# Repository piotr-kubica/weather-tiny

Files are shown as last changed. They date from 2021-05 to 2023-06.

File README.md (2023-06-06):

BTC  


# Tiny weather station based on TTGO T5 V2.3.1 (ESP32 with 2.13" e-ink display)

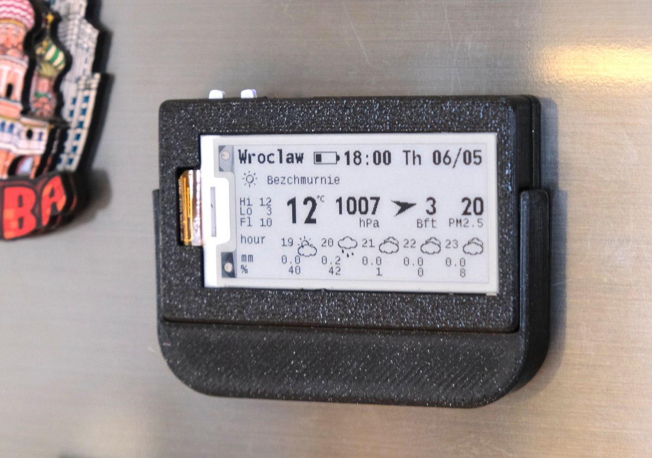
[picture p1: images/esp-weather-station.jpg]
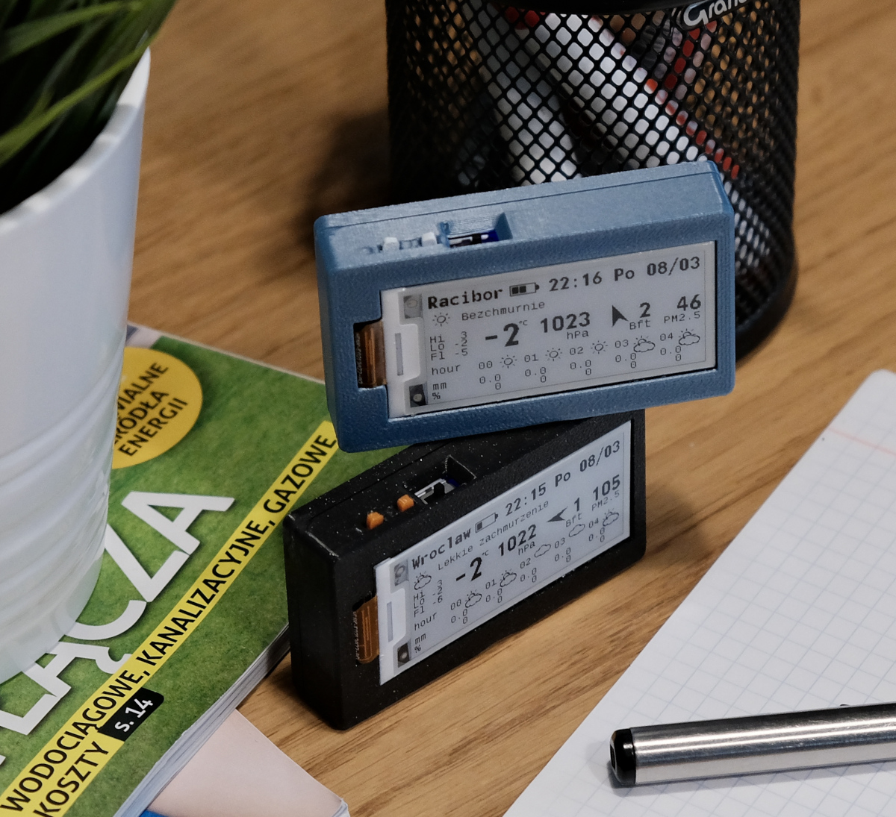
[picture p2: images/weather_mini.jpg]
[](/images/esp-weather-station.jpg) [](/images/weather_mini.jpg) 

### This project is licensed under GNU General Public License v2.0
The GNU GPL is the most widely used free software license and has a strong copyleft requirement. When distributing derived works, the source code of the work must be made available under the same license. There are multiple variants of the GNU GPL, each with different requirements.

### 🔸NOTE🔸
Second version of the firmware is currently being developed.
The goals include: enhanced performance, increased (4+ weeks) battery life, easier configurability, integration with external systems.

### Features

- wireless and rechargable
- weather description including temperature, pressure, wind
- rain forecast
- air quality index
- multiple locations
- easy wireless setup using smartphone/PC
- fridge mount
- refreshes every 15 min.

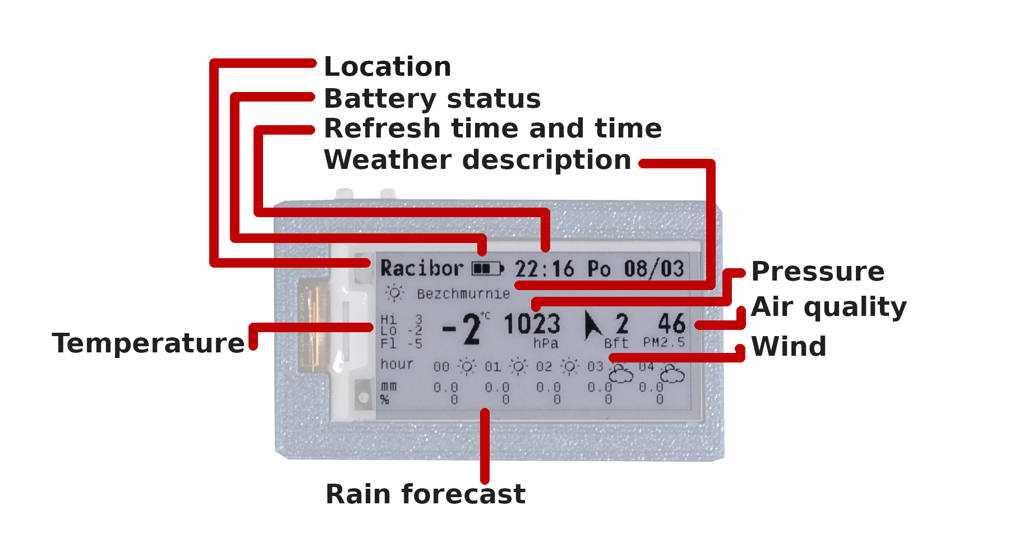
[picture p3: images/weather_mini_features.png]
[](/images/weather_mini_features.png)

### User guide

#### Device configuration

Turn on device. 
Reset to enable configuration.
Connect to `weather-wifi` device access point.
Go to 192.168.4.1/config if not redirected.
Provide wireless lan ssid and password.
Provide locations for which information should be fetched.
Submit config form.
After a successful validation device displays weather information for given location.

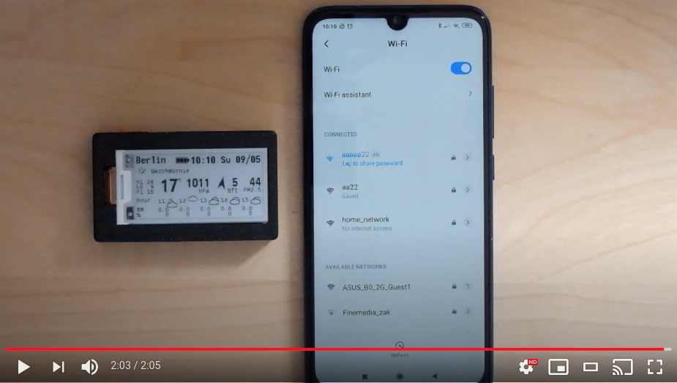
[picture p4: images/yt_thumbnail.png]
YT video thumbnail (https://youtu.be/SJgQPxBXJxA)


#### Device usage
Switch between locations using top left button. \
Refresh current location using top right button. \
Reset device using bottom button. \
Turn on/off device using top switch.
\
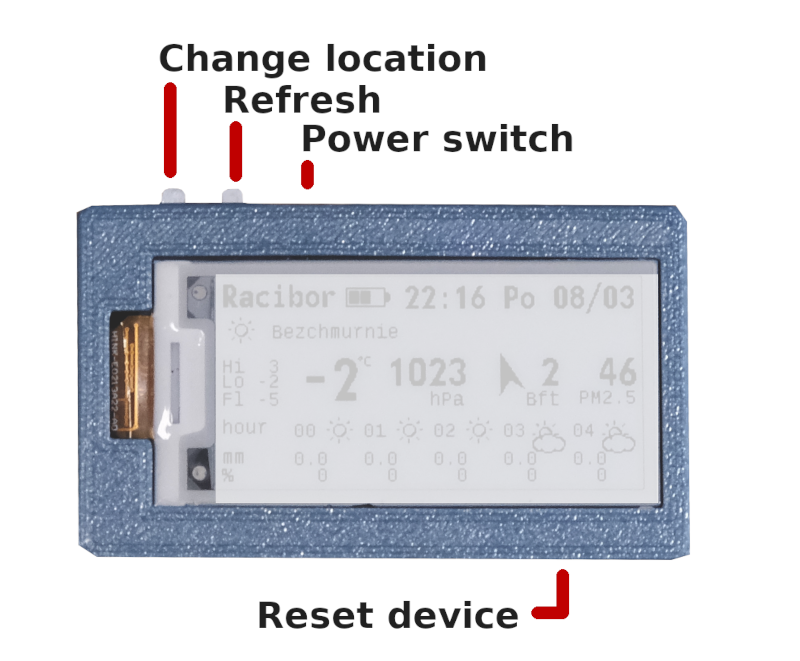
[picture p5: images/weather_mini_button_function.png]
[](/images/weather_mini_button_function.png)

### Hardware
To assemble the device yourself you will need
- TTGO T5 V2.3
- small LiPo battery cell with JST-BEC connector (980mAh 3.7V, size: 50x34x6mm)
- 3D printed case (see: stl files)
- M3 bolt (6mm long) [4]
- magnet 5x12mm (for fridge mount) [5]
- 10k resistor [1]
- thermo sleeve [3]
- small tactile button 4.5x4.5x3mm [2]
- (optional) poly foam or similar to put inside case with battery, so it does not move

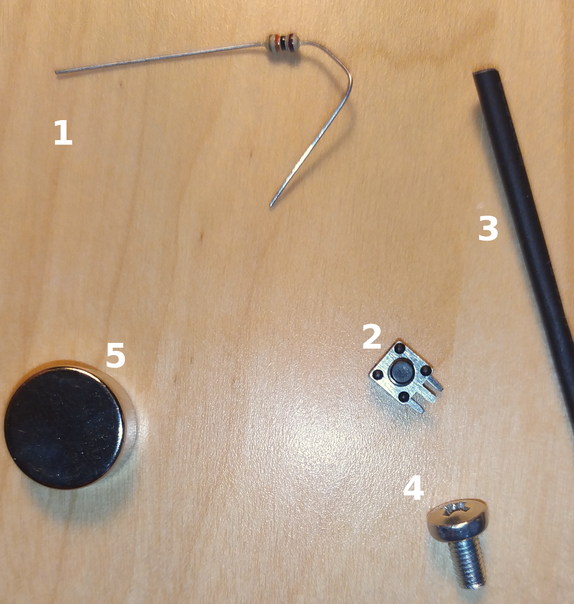
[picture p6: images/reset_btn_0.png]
[](/images/reset_btn_0.png)
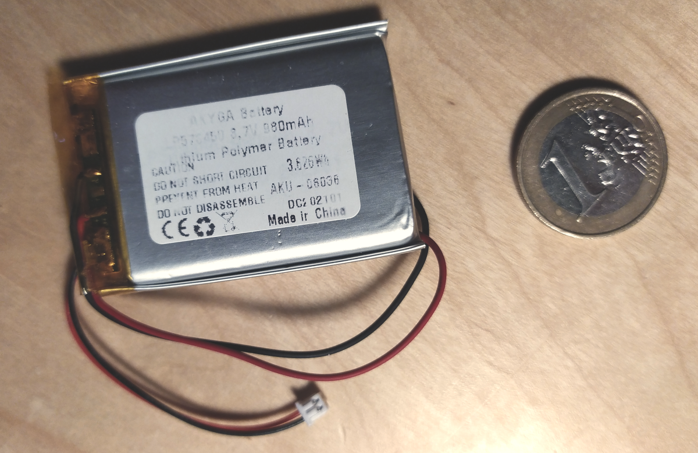
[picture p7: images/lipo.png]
[](/images/lipo.png)

### Assembly
Device comes with two buttons (used for refresh and location change).
The missing reset device button needs to be added by using tactile button and a pull-down resistor.
Create the pull-down resistor by soldering the resistor to GND and pin 34.
Solder the tactile button to pins 34 and 3V3.

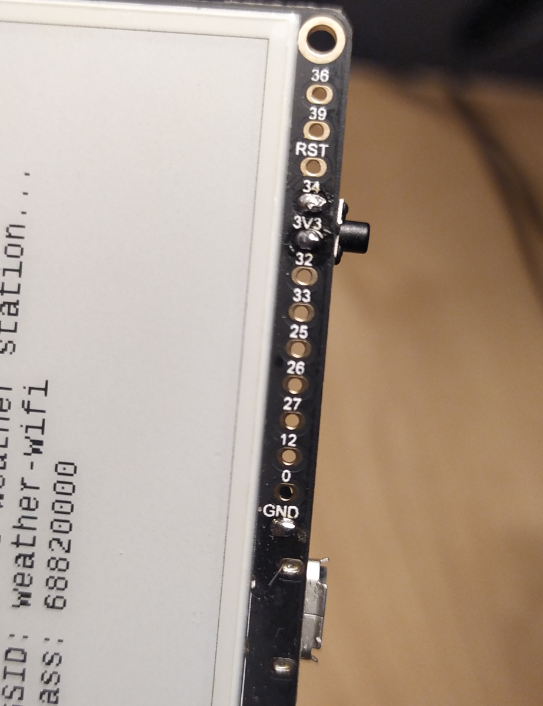
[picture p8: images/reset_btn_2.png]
[](/images/reset_btn_2.png)
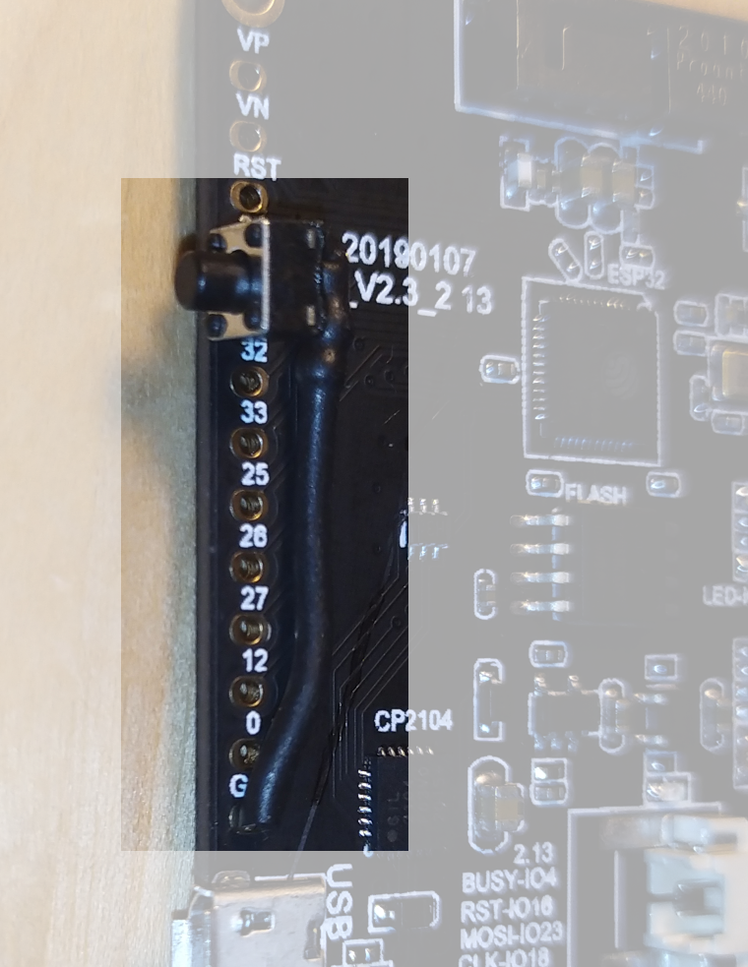
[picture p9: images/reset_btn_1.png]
[](/images/reset_btn_1.png) 

Insert TTGO to the 3D printed case. Connect the LiPo cell. 
Mount the case using M3 bolt.

### Software

#### License
Project source code is licensed under GPL2 (including source code and stl).
This does not include external libraries and used fonts.

#### Installation
##### Setup Arduino IDE to be used with ESP32.
You can do this in this tutorial
https://randomnerdtutorials.com/installing-the-esp32-board-in-arduino-ide-windows-instructions/

##### Install external libs
- Adafruit GFX Library
- GxEPD.h - includes e-ink screen drivers. I have used GxGDE0213B72B or GxDEPG0213BN depending on device display version
- ArduinoJson - for handling API responses 
- AsyncTCP - used for API requests
- ESPAsyncWebServer - used for config server
- Preferences - used for data storage

You can find GxGDE0213B72B and GxDEPG0213BN drivers <a href="https://github.com/Xinyuan-LilyGO/LilyGO-T-Echo/tree/7066ced313bf4ca941c6edbcb20ea3b1aaf0ea95/lib/GxEPD/src">here</a>
  
Use font files generated by fontconvert which can be found inside libraries/Adafruit_GFX_library/Fonts.
You can also download these fonts (free to use) and use fontconvert tool to create them yourself.

##### API keys
External APIs are used to fetch data. 
These are free to use services:
- https://positionstack.com/ to fetch location position
- https://aqicn.org/api/pl/ for air quality
- https://openweathermap.org/api for weather data
- https://timezonedb.com/api for date and time

Register and obtain the keys. Then replace the api keys in config.h file.

##### Upload sketch to device
Verify and upload the weather_mini.ino sketch.
After successful upload turn on the device and configure it as shown in [device configuration](#device-configuration) section.
See the example output from [serial monitor](monitor_log.txt) for a successful device configuration.

### Support

If you have found this project useful you can buy me a cup of coffee 







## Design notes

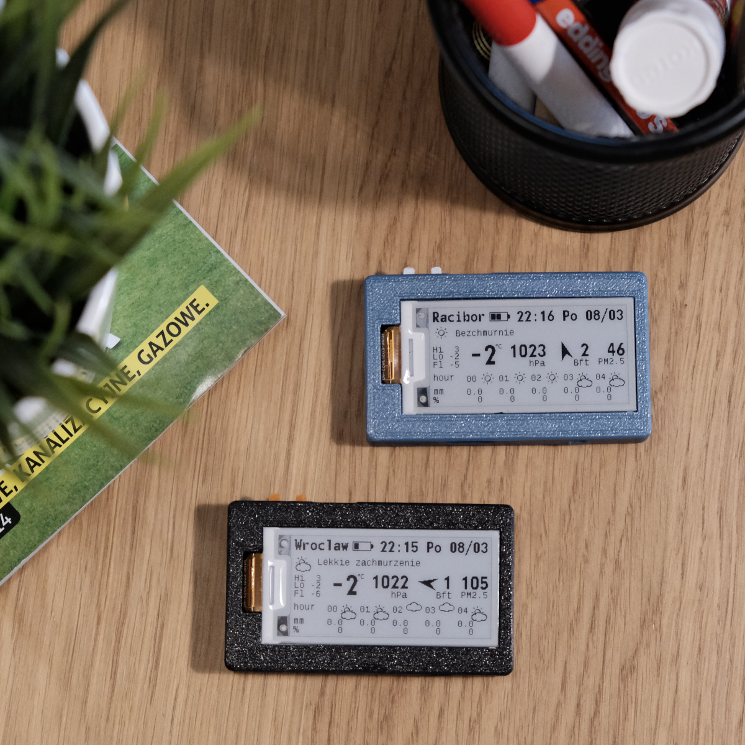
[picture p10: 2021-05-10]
images/weather_mini2.jpg

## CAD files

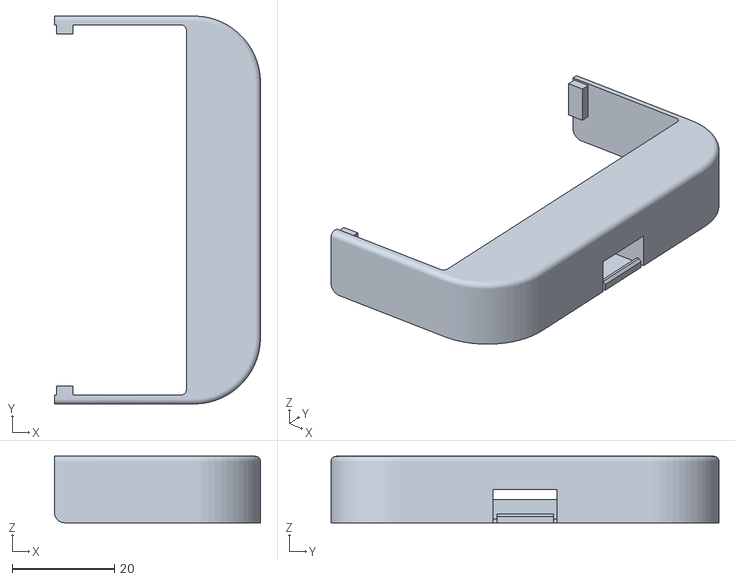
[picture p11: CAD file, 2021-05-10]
stl/mount.stl
40.2 x 75.8 x 13.0

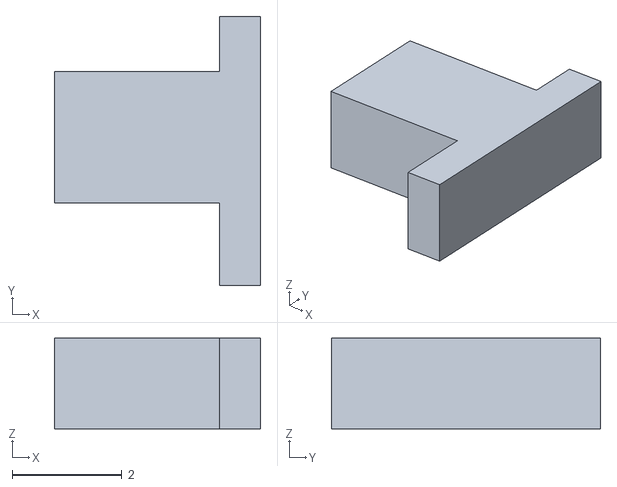
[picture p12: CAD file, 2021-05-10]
stl/btn-right.stl
3.75 x 4.90 x 1.65

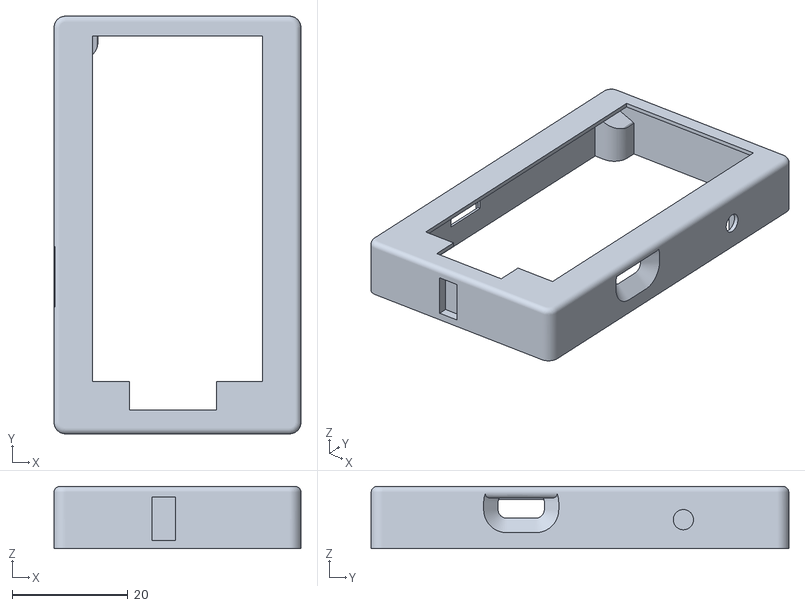
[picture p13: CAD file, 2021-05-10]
stl/front.stl
42.8 x 72.3 x 10.8

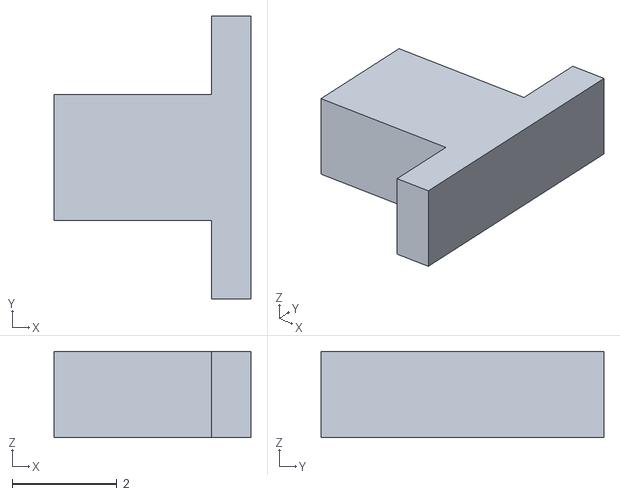
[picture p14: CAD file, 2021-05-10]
stl/btn-left.stl
3.75 x 5.40 x 1.65

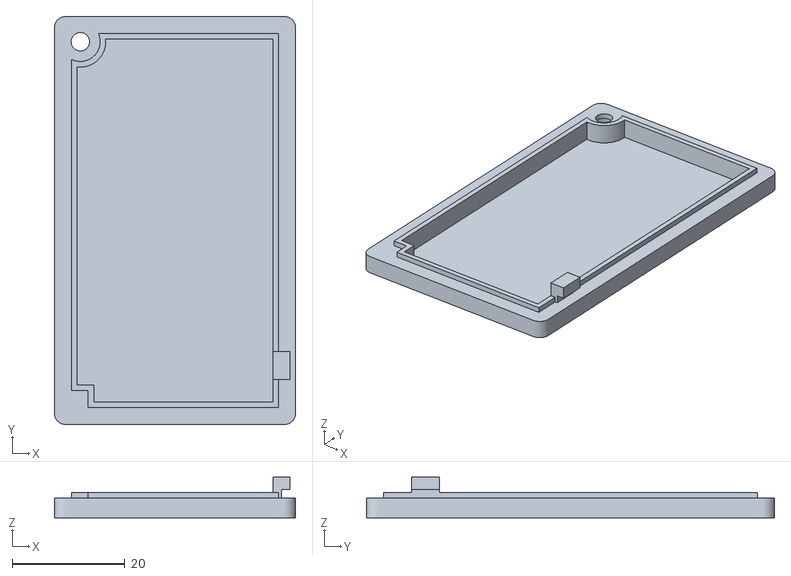
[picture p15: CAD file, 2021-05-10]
stl/back.stl
42.8 x 72.3 x 7.25

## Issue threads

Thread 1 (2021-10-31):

Add pressure trend indicating arrow

piotr-kubica, 2021-10-31:
Add pressure trend indicating arrow below pressure value pointing upwards/downwards or no arrow for no big change in pressure.

rdulak, 2022-02-11:
Great project !!! Revelation !!!
Unfortunately I stopped at the connection with api.positionstack.
I get the response "Error 520 Web server is returning an unknown error".
Is a Free account enough for the module to work.
Even sending a request from the browser I do not get an answer.
I ask for osugestions. Thank you.

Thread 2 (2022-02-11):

api.positionstack ---> Error 520

rdulak, 2022-02-11:
Great project !!! Revelation !!!
Unfortunately I stopped at the connection with api.positionstack.
I get the response "Error 520 Web server is returning an unknown error".
Is a Free account enough for the module to work.
Even sending a request from the browser I do not get an answer.
I ask for osugestions. Thank you.

piotr-kubica, 2022-02-11:
> Great project !!! Revelation !!!
Thank you :)

> I get the response "Error 520 Web server is returning an unknown error".
Seems to be a server side problem. You could contact positionstack and ask if your request is valid.

> Is a Free account enough for the module to work.
with free tier should be ok (25.000 Requests at the time of writing)

Device does request (by default) every 15 mins so 15*24 per day -> this is optimistic estimation, because in case the request fails there will be a retry.

Also I see possible improvement: request during night could be done sparsely (1/hour) and during datetime reduce from 4 to 3 per hour to improve battery life

rdulak, 2022-02-11:
Is your system working fine at the moment?
To my eye, something is on the server side ...
"All systems down" :(
https://status.positionstack.com/

piotr-kubica, 2022-02-11:
same for me

Closed 2022-02-11.

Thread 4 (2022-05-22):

Daily forecast for rain

mattcalavera, 2022-05-22:
Hi! Many thanks for your beautiful works!!
Could please be possibile to switch between hourly rain forecast and daily rain forecast, instead (or in the same way) now we switch from the two location??

Thanks
#Enhancements

piotr-kubica, 2022-06-03:
No problem. Feel free to change code to your liking

piotr-kubica, 2023-06-06:
@mattcalavera
the location change happens on button press which wakes up the device. The cause of this wakeup is handled in this function https://github.com/piotr-kubica/weather-tiny/blob/19708bc4932226a28e3403b3fe56d250bcc236e3/weather_tiny/weather_tiny.ino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

The response from OpenWeatherApi is handled in this function https://github.com/piotr-kubica/weather-tiny/blob/19708bc4932226a28e3403b3fe56d250bcc236e3/weather_tiny/weather_tiny.ino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

Also, look up the API to see how it's structured https://openweathermap.org/api

I hope this helps you with your changes.

mattcalavera, 2023-06-09:
Hi! I start with saving forecasts for next 5 days instead of next 2 days : in

https://github.com/piotr-kubica/weather-tiny/blob/19708bc4932226a28e3403b3fe56d250bcc236e3/weather_tiny/api_request.h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

How can I save forecasts for next 5 days?? (in the api response there are next 7 days!)

mattcalavera, 2023-06-10:
Ok, after a few work I obtain next 5 days rain forecast.... I'll fork this project with the new code if someone is interested

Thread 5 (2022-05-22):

Battery Icon

mattcalavera, 2022-05-22:
the battery icon remain still with the bolt inside as if it where ever on charge also when it's powered only by battery

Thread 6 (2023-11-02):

2.13英寸得屏幕显示不全，这个应该是2.3英寸屏幕尺寸得项目。

plutosherry, 2023-11-02:
2.13英寸得屏幕显示不全，这个应该是2.3英寸屏幕尺寸得项目。
修改了

`
//#define SCREEN_WIDTH   250
//#define SCREEN_HEIGHT  122

#define SCREEN_WIDTH   212
#define SCREEN_HEIGHT  104
`
但依旧不能完整显示

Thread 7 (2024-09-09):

Compile Error with latest library versions

bix2702, 2024-09-09:
I just found your very nice weather tiny project and tried to replicate. I used the latest versions of all libraries and Arduino Studio. Unfortunately the build fails, probably because of changes in some libs. Especially the ArdunioJson and AsyncTCP got a lot of changes.
Maybe it's just smal thing but it's too complex for me the rewrite it.

Would you mind to try to compile it against the latest libraries? Or could you write which versions of each library you used?

piotr-kubica, 2024-09-10:
Hi, thanks for writing!

> Or could you write which versions of each library you used?

I'm sorry I didn't put the version number next to libraries.
Your best bet would be to download all libs from around May 2021 and then trying to compile.

> Would you mind to try to compile it against the latest libraries?

Sorry, I've already moved to implementing second iteration of this device.
I hope I can share the ready project with you as soon as I am ready to release some meaningful and working code.

bix2702, 2024-09-11:
Hi Piotr,
thx for quick answer! I will try and report.

Of course, I would be very interessted in your second iteration.

Kind  Regards

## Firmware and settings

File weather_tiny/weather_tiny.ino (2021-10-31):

// ----------------------------------
// DISPLAY --------------------------
// ----------------------------------
#include <SPI.h>
#include <GxEPD.h>

#include <GxGDE0213B72B/GxGDE0213B72B.h> // 2.13" b/w
// #include <GxDEPG0213BN/GxDEPG0213BN.h>  // 2.13" b/w newer panel

#include <GxIO/GxIO_SPI/GxIO_SPI.h>
#include <GxIO/GxIO.h>

#define SPI_MOSI 23
#define SPI_MISO -1
#define SPI_CLK 18
#define ELINK_SS 5
#define ELINK_BUSY 4
#define ELINK_RESET 16
#define ELINK_DC 17

GxIO_Class io(SPI, ELINK_SS, ELINK_DC, ELINK_RESET);
GxEPD_Class display(io, ELINK_RESET, ELINK_BUSY);

#define SCREEN_WIDTH   250
#define SCREEN_HEIGHT  122

// ----------------------------------
// LIBS -----------------------------
// ----------------------------------
#define ARDUINOJSON_USE_DOUBLE 1

#include <WiFi.h>
#include <HTTPClient.h>
#include <ArduinoJson.h>
#include <time.h>
#include <DNSServer.h>
#include <AsyncTCP.h>
#include <ESPAsyncWebServer.h>
#include <rom/rtc.h> 
#include <Preferences.h>

#define ADC_PIN 35
#define WAKE_BTN_PIN 39

// ----------------------------------
// FONTS ----------------------------
// ----------------------------------

#include <Fonts/Monofonto10pt.h>
#include <Fonts/Monofonto12pt.h>
#include <Fonts/Monofonto18pt.h>
#include <Fonts/MeteoCons8pt.h>
#include <Fonts/MeteoCons10pt.h>
#include <Fonts/Cousine6pt.h>

// ----------------------------------
// LOCAL FILES AND DECLARATIONS -----
// ----------------------------------

#include "fmt.h"
#include "i18n.h"
#include "config.h"
#include "units.h"
#include "api_request.h"
#include "display.h"
#include "view.h"

#define MEMORY_ID "mem"
#define LOC_MEMORY_ID "loc"

#define NOT_SET_MODE 0
#define CONFIG_MODE 1
#define VALIDATING_MODE 2
#define OPERATING_MODE 3

// http server for obtaining configuration
DNSServer dnsServer;
AsyncWebServer server(80);
Preferences preferences;

int cached_MODE = 0;
int curr_loc = 0;

struct WeatherRequest weather_request;
struct AirQualityRequest airquality_request;
struct GeocodingNominatimRequest location_request;
struct TimeZoneDbRequest datetime_request;

int location_cnt = 0;
struct Location location[2];
struct WifiCredentials wifi;
struct View view;

int get_mode(bool cached_mode=false);
DynamicJsonDocument deserialize(WiFiClient& resp_stream, const int size, bool is_embeded=false);


// ----------------------------------
// FUNCTION DEFINITIONS -------------
// ----------------------------------

template<typename T>
T value_or_default(JsonObject jobj, String key, T default_value) {
    if (!jobj.containsKey(key)) {
        return default_value;
    } else {
        return jobj[key];
    }
}


template<typename T>
T nested_value_or_default(JsonObject parent_jobj, String key, String nested_key, T default_value) {
    if (!parent_jobj.containsKey(key)) {
        return default_value;
    } else {
        return parent_jobj[key][nested_key];
    }
}


void update_header_view(View& view, bool data_updated) {
    view.location = location[curr_loc].name.substring(0,7);
    view.battery_percent = get_battery_percent(analogRead(ADC_PIN));
    int percent_display = view.battery_percent;
    
    if (percent_display > 100) {
        percent_display = 100;
    }
    view.battery_percent_display = String(percent_display) + "%";
    view.datetime = header_datetime(&datetime_request.response.dt, data_updated);
}


void update_air_quality_view(View& view, bool data_updated) {
    if (!data_updated) {
        return;
    }
    view.aq_pm25 = left_pad(String(airquality_request.response.pm25), 3);
    view.aq_pm25_unit = "PM2.5";
}


void update_weather_view(View& view, bool data_updated) {
    if (!data_updated) {
        return;
    }
    view.weather_icon = String(icon2meteo_font(weather_request.hourly[0].icon));
    
    String descr = weather_request.hourly[0].descr;
    view.weather_desc = capitalize(descr);
    
    view.temp_curr = left_pad(String(weather_request.hourly[0].temp), 3);
    view.temp_unit = '*';  // celsius
    view.temp_high = "Hi" + left_pad(String(weather_request.hourly[0].max_t), 3);
    view.temp_low = "Lo" + left_pad(String(weather_request.hourly[0].min_t), 3);
    view.temp_feel = "Fl" + left_pad(String(weather_request.hourly[0].feel_t), 3);

    view.pressure = left_pad(String(weather_request.hourly[0].pressure), 4);
    view.pressure_unit = "hPa";

    view.wind = left_pad(String(weather_request.hourly[0].wind_bft), 2);
    view.wind_deg = weather_request.hourly[0].wind_deg;

    for (int i = 0; i < PERCIP_SIZE; i++) {
        view.percip_time[i] = ts2H(weather_request.rain[i].date_ts + datetime_request.response.gmt_offset);
        view.percip_icon[i] = String(icon2meteo_font(weather_request.rain[i].icon));

        float cumulative_percip = weather_request.rain[i].snow + weather_request.rain[i].rain;
        if (cumulative_percip > 0) {
            view.percic_pop[i] = left_pad(fmt_2f1(cumulative_percip), 4);
        } else {
            view.percic_pop[i] = left_pad(String(min(weather_request.rain[i].pop, 99)) + "%", 4);
        }

        // temp TODO rename from percip
        view.percip[i] = fmt_2f1(weather_request.rain[i].feel_t);
    }
}


void update_location(GeocodingNominatimResponse& location_resp, JsonObject& jobj) {
    location_resp.lat = jobj["data"][0]["latitude"].as<float>();
    location_resp.lon = jobj["data"][0]["longitude"].as<float>();
    location_resp.label = String(jobj["data"][0]["label"].as<char*>()).substring(0, 25);
}


void update_datetime(TimeZoneDbResponse& datetime_resp, JsonObject& jobj) {
    datetime_resp.dt = jobj["timestamp"].as<int>();
    datetime_resp.gmt_offset = jobj["gmtOffset"].as<int>();
    datetime_resp.dst = jobj["dst"].as<int>();
}


void update_current_weather(WeatherResponseHourly& hourly, JsonObject& root) {
    hourly.date_ts = root["current"]["dt"].as<int>();
    hourly.sunr_ts = root["current"]["sunrise"].as<int>();
    hourly.suns_ts = root["current"]["sunset"].as<int>();
    hourly.temp = kelv2cels(root["current"]["temp"].as<float>());
    hourly.feel_t = kelv2cels(root["current"]["feels_like"].as<float>());
    hourly.max_t = kelv2cels(root["daily"][0]["temp"]["max"].as<float>());
    hourly.min_t = kelv2cels(root["daily"][0]["temp"]["min"].as<float>());
    hourly.pressure = root["current"]["pressure"].as<int>();
    hourly.clouds = root["current"]["clouds"].as<int>();
    hourly.wind_bft = wind_ms2bft(root["current"]["wind_speed"].as<float>());
    hourly.wind_deg = root["current"]["wind_deg"].as<int>();
    hourly.icon = String(root["current"]["weather"][0]["icon"].as<char*>()).substring(0, 2);
    hourly.descr = root["current"]["weather"][0]["description"].as<char*>();
    hourly.pop = round(root["hourly"][1]["pop"].as<float>() * 100);
    hourly.snow = value_or_default(root["current"], "snow", 0.0f);
    hourly.rain = value_or_default(root["current"], "rain", 0.0f);
}


void update_forecast_weather(WeatherResponseDaily& daily, JsonObject& root, const int day_offset) {
    daily.date_ts = root["daily"][day_offset]["dt"].as<int>();
    daily.max_t = kelv2cels(root["daily"][day_offset]["temp"]["max"].as<float>());
    daily.min_t = kelv2cels(root["daily"][day_offset]["temp"]["min"].as<float>());
    daily.wind_bft = wind_ms2bft(root["daily"][day_offset]["wind_speed"].as<float>());
    daily.wind_deg = root["daily"][day_offset]["wind_deg"].as<int>();
    daily.pop = round(root["daily"][day_offset]["pop"].as<float>() * 100);
    daily.snow = value_or_default(root["daily"][day_offset], "snow", 0.0f);
    daily.rain = value_or_default(root["daily"][day_offset], "rain", 0.0f);
}


void update_percip_forecast(WeatherResponseRainHourly& percip, JsonObject& root, const int hour_offset) {
    percip.date_ts = root["hourly"][hour_offset]["dt"].as<int>();
    percip.pop = round(root["hourly"][hour_offset]["pop"].as<float>() * 100);
    percip.snow = nested_value_or_default(root["hourly"][hour_offset], "snow", "1h", 0.0f);
    percip.rain = nested_value_or_default(root["hourly"][hour_offset], "rain", "1h", 0.0f);
    percip.feel_t = kelv2cels1(root["hourly"][hour_offset]["feels_like"].as<float>());
    percip.icon = String(root["hourly"][hour_offset]["weather"][0]["icon"].as<char*>()).substring(0, 2);
}


bool location_handler(WiFiClient& resp_stream, Request request) {
    const int json_size = 20 * 1024;
    DynamicJsonDocument doc = deserialize(resp_stream, json_size, true);
    JsonObject api_resp = doc.as<JsonObject>();

    if (api_resp.isNull()) {
        return false;
    }
    location_request = GeocodingNominatimRequest(request);
    GeocodingNominatimResponse& location_resp = location_request.response;
    Serial.print("Geocoding...");
    update_location(location_resp, api_resp);
    location_resp.print();
    return true;
}


bool datetime_handler(WiFiClient& resp_stream, Request request) {
    const int json_size = 10 * 1024;
    DynamicJsonDocument doc = deserialize(resp_stream, json_size, true);
    JsonObject api_resp = doc.as<JsonObject>();

    if (api_resp.isNull()) {
        return false;
    }
    datetime_request = TimeZoneDbRequest(request);
    TimeZoneDbResponse& datetime_response = datetime_request.response;
    update_datetime(datetime_response, api_resp);
    datetime_response.print();
    return true;
}
    

bool weather_handler(WiFiClient& resp_stream, Request request) {
    const int json_size = 35 * 1024;
    DynamicJsonDocument doc = deserialize(resp_stream, json_size);
    JsonObject api_resp = doc.as<JsonObject>();

    if (api_resp.isNull()) {
        return false;
    }
    weather_request = WeatherRequest(request);
    WeatherResponseHourly& hourly = weather_request.hourly[0];
    WeatherResponseDaily& next_day = weather_request.daily[0];
    WeatherResponseDaily& second_next_day = weather_request.daily[1];

    update_current_weather(hourly, api_resp);
    hourly.print();
    update_forecast_weather(next_day, api_resp, 1);
    next_day.print();
    update_forecast_weather(second_next_day, api_resp, 2);
    second_next_day.print();

    for (int hour = 0; hour < 5; hour++) {
        int offset = hour + 1;
        update_percip_forecast(weather_request.rain[hour], api_resp, offset);
        weather_request.rain[hour].print();
    }
    return true;
}


bool air_quality_handler(WiFiClient& resp_stream, Request request) {
    const int json_size = 6 * 1024;
    DynamicJsonDocument doc = deserialize(resp_stream, json_size);
    JsonObject api_resp = doc.as<JsonObject>();
    
    if (api_resp.isNull()) {
        return false;
    }
    if (!String(api_resp["status"].as<char*>()).equals("ok")) {
        return false;
    }
    airquality_request = AirQualityRequest(request);
    
    if (api_resp["data"]["iaqi"].containsKey("pm25")) {
        airquality_request.response.pm25 = api_resp["data"]["iaqi"]["pm25"]["v"].as<int>();
    } else if (api_resp["data"]["forecast"]["daily"].containsKey("pm25")) {
        airquality_request.response.pm25 = api_resp["data"]["forecast"]["daily"]["pm25"][0]["max"].as<int>();
    }
    airquality_request.response.print();
    
    return true;
}


DynamicJsonDocument deserialize(WiFiClient& resp_stream, const int size, bool is_embeded) {
    // https://arduinojson.org/v6/assistant/
    Serial.print("\nDeserializing json, size:" + String(size) + " bytes...");
    DynamicJsonDocument doc(size);
    DeserializationError error;
    
    if (is_embeded) {
        String stream_as_string = resp_stream.readString();
        int begin = stream_as_string.indexOf('{');
        int end = stream_as_string.lastIndexOf('}');
        Serial.print("\nEmbeded json algorithm obtained document...\n");
        String trimmed_json = stream_as_string.substring(begin, end+1);
        Serial.println(trimmed_json);
        error = deserializeJson(doc, trimmed_json);
    } else {
        error = deserializeJson(doc, resp_stream);
    }
    if (error) {
        Serial.print(F("\ndeserialization error:"));
        Serial.println(error.c_str());
    } else {
        Serial.println("deserialized.");
    }
    Serial.println("");
    return doc;
}


int get_battery_percent(int adc_value) {
    float voltage = adc_value / 4095.0 * 7.5;
    Serial.println("Battery voltage ~" + String(voltage) + "V");
    if (voltage > 4.35) {
        return 101;  // charging / DC powered
    }
    if (voltage > 4.2) {
        return 100;
    } 
    if (voltage < 3.3) {
        return 1;
    }
    int percent = (int)((voltage - 3.3)/(4.1 - 3.3)*99) + 1;
    Serial.println("Battery percent: " + String(percent) + "%");
    return percent;
}


bool http_request_data(WiFiClient& client, Request request, unsigned int retry=3) {
    
    bool ret_val = false;

    while(!ret_val && retry--) {
        ret_val = true;
        client.stop();
        HTTPClient http;
        Serial.printf("\nHTTP connecting to %s%s [retry left: %s]", request.server.c_str(), request.path.c_str(), String(retry).c_str());
        http.begin(client, request.server, 80, request.path);
        int http_code = http.GET();
        
        if(http_code == HTTP_CODE_OK) {
            Serial.println("\nHTTP connection established");
            if (!request.handler(http.getStream(), request)) {
                ret_val = false;
            }
        } else {
            Serial.printf("\nHTTP connection failed %s, error: %s \n\n", String(http_code).c_str(), http.errorToString(http_code).c_str());
            ret_val = false;
        }
        client.stop();
        http.end();
    }
    return ret_val;
}


bool connect_to_wifi(unsigned int retry=5) {

    int wifi_conn_status = WL_IDLE_STATUS;
    WiFi.mode(WIFI_STA); // Access Point mode off
    WiFi.setAutoConnect(true);
    WiFi.setAutoReconnect(true);

    while(wifi_conn_status != WL_CONNECTED && retry--) {
        Serial.println("\nConnecting to: " + wifi.ssid + " [retry left: " + retry +"]");
        unsigned long start = millis();
        wifi_conn_status = WiFi.begin(wifi.ssid.c_str(), wifi.pass.c_str());
        
        while (true) {
            if (millis() > start + 10000) { // 10s
                break;
            }
            delay(100);
    
            wifi_conn_status = WiFi.status();
            
            if (wifi_conn_status == WL_CONNECTED) {
                Serial.println("Wifi connected. IP: " + WiFi.localIP().toString());    
                break;
            } else if(wifi_conn_status == WL_CONNECT_FAILED) {
                Serial.println("Wifi failed to connect.");
                break;
            }
        }
        if (wifi_conn_status == WL_CONNECTED) {
            return true;
        }
        delay(2000); // 2sec
    }
    return false;
}

void print_reset_reason(RESET_REASON reason) {
    switch ( reason) {
        case 1 : Serial.print("POWERON_RESET"); break;
        case 3 : Serial.print("SW_RESET"); break;
        case 4 : Serial.print("OWDT_RESET"); break;
        case 5 : Serial.print("DEEPSLEEP_RESET"); break;
        case 6 : Serial.print("SDIO_RESET"); break; 
        case 7 : Serial.print("TG0WDT_SYS_RESET"); break;
        case 8 : Serial.print("TG1WDT_SYS_RESET"); break;
        case 9 : Serial.print("RTCWDT_SYS_RESET"); break;
        case 10 : Serial.print("INTRUSION_RESET"); break;
        case 11 : Serial.print("TGWDT_CPU_RESET"); break;
        case 12 : Serial.print("SW_CPU_RESET"); break;
        case 13 : Serial.print("RTCWDT_CPU_RESET"); break;
        case 14 : Serial.print("EXT_CPU_RESET"); break;
        case 15 : Serial.print("RTCWDT_BROWN_OUT_RESET"); break;
        case 16 : Serial.print("RTCWDT_RTC_RESET"); break;
        default : Serial.print("UNKNOWN");
    }
}


void wakeup_reason() {
    esp_sleep_wakeup_cause_t wakeup_reason;
    wakeup_reason = esp_sleep_get_wakeup_cause();
    
    switch(wakeup_reason){
        Serial.println("Location variable: " + String(curr_loc));
        
        case ESP_SLEEP_WAKEUP_EXT0 : 
            Serial.println("\nWakeup by ext signal RTC_IO -> GPIO39"); 
            if (get_mode() == OPERATING_MODE) {
                // Toggle between 2 screens caused by button press WAKE_BTN_PIN
                if (location_cnt > 1) {
                    curr_loc = (curr_loc+1) % 2;
                    // save location
                    save_location_to_memory(curr_loc);
                }
            }        
            break;
            
        case ESP_SLEEP_WAKEUP_EXT1 : 
            Serial.println("Wakeup by ext signal RTC_CNTL -> GPIO34"); 
            set_mode_and_reboot(CONFIG_MODE);
            break;
            
        case ESP_SLEEP_WAKEUP_TIMER : Serial.println("Wakeup by timer"); break;
        case ESP_SLEEP_WAKEUP_TOUCHPAD : Serial.println("Wakeup by touchpad"); break;
        case ESP_SLEEP_WAKEUP_ULP : Serial.println("Wakeup by ULP program"); break;
        default : Serial.printf("Wakeup not caused by deep sleep: %d\n", wakeup_reason); break;
    }
    Serial.print("CPU0 reset reason: ");
    print_reset_reason(rtc_get_reset_reason(0));
    Serial.print(",  CPU1 reset reason: ");
    print_reset_reason(rtc_get_reset_reason(1));
    Serial.println();
}


void enable_timed_sleep(int interval_minutes) {
    // sleep and wake up round minutes, ex every 15 mins
    // will wake up at 7:15, 7:30, 7:45 etc.

    struct tm* timeinfo;
    timeinfo = localtime(&datetime_request.response.dt);
    int current_time_min = timeinfo->tm_min;
    int current_time_sec = timeinfo->tm_sec;
    int sleep_minutes_left = interval_minutes - current_time_min % interval_minutes - 1;  // - 1 minute running in seconds
    int sleep_seconds_left = 60 - current_time_sec;
    int sleep_time_seconds = sleep_minutes_left * 60 + sleep_seconds_left;
    
    long sleep_time_micro_sec = sleep_time_seconds * 1000 * 1000;
    esp_sleep_enable_timer_wakeup(sleep_time_micro_sec);
    Serial.printf("\nWake up in %d minutes and %d seconds", sleep_minutes_left, sleep_seconds_left);
}


void begin_deep_sleep() {
#ifdef BUILTIN_LED
    pinMode(BUILTIN_LED, INPUT); // If it's On, turn it off and some boards use GPIO-5 for SPI-SS, which remains low after screen use
    digitalWrite(BUILTIN_LED, HIGH);
#endif

    display.powerDown();
    disconnect_from_wifi();
    
#ifdef WAKE_BTN_PIN
    //  https://docs.espressif.com/projects/esp-idf/en/latest/esp32/api-reference/system/sleep_modes.html
    esp_sleep_enable_ext0_wakeup((gpio_num_t)WAKE_BTN_PIN, LOW);
#endif

    // config triggering button
#define BUTTON_PIN_BITMASK 0x0400000000 // pin 34
    esp_sleep_enable_ext1_wakeup(BUTTON_PIN_BITMASK, ESP_EXT1_WAKEUP_ANY_HIGH);

    // this should lower power consumtion
    // https://www.reddit.com/r/esp32/comments/idinjr/36ma_deep_sleep_in_an_eink_ttgo_t5_v23/
    pinMode(13, OUTPUT);
    digitalWrite(13, HIGH);
    gpio_deep_sleep_hold_en();

    // start sleep
    esp_deep_sleep_start();
}


void disconnect_from_wifi() {
    WiFi.disconnect();
    WiFi.mode(WIFI_OFF);
}


void http_resource_not_found(AsyncWebServerRequest *request) {
    request->send(404, "text/plain", "Not found");
}


String get_param(AsyncWebServerRequest *request, String name) {
    String value;
    if (request->hasParam(name, true)) {
        value = request->getParam(name, true)->value();
        return value;
    }
    return "";
}


String get_param(AsyncWebServerRequest *request, String name, bool& exists) {
    String value;
    if (request->hasParam(name, true)) {
        value = request->getParam(name, true)->value();

        if (value.equals("")) {
            exists = false;
            return "";        
        }
        exists = exists && true;
        return value;
    }
    exists = false;
    return "";
}


String create_validation_message(bool valid_wifi, bool valid_location_1, bool valid_location_2) {
    String wifi_error_msg = "";
    String location_1_error_msg = "";
    String location_2_error_msg = "";
        
    if (!valid_wifi) {
        wifi_error_msg = "Missing WIFI credentials. Please provide SSID and password.\n";
    }        
    if (!valid_location_1) {
        location_1_error_msg = "Invalid location 1. Please provide name and postition.";
    }
    if (!valid_location_2) {
        location_2_error_msg = "Incomplete location 2 data. Location will be omitted.";
    }
    String message_result = "";
    String message_color;

    if (!valid_wifi || !valid_location_1) {
        message_result = "in";  // add prefix for valid
        message_color = "red";
    } else {
        message_color = "green";
    }
    String response_msg = String("<h1>Weather Station Configuration</h1><br><br>") +
    String("<h2 style=\"color:") + message_color + String("\">Configuration is ") + message_result + String("valid.</h2><br>") +
    String("<h3>") + wifi_error_msg + String("</h3><br>") +
    String("<h3>") + location_1_error_msg + String("</h3><br>") +
    String("<h3>") + location_2_error_msg + String("</h3><br>");
        
    return response_msg;
}


void read_config_from_memory() {
    Serial.println("Read config from memory...");
    preferences.begin(MEMORY_ID, true);  // first param true means 'read only'

    wifi.ssid = preferences.getString("ssid");
    wifi.pass = preferences.getString("pass");
    wifi.print();

    location_cnt = preferences.getInt("locations");  // global variable
    Serial.println("Locations: " + String(location_cnt));

    location[0].name = preferences.getString("loc1", "");
    location[0].lat = preferences.getFloat("lat1", 0.0f);
    location[0].lon = preferences.getFloat("lon1", 0.0f);
    location[0].print();

    if (location_cnt > 1) {
        location[1].name = preferences.getString("loc2", "");
        location[1].lat = preferences.getFloat("lat2", 0.0f);
        location[1].lon = preferences.getFloat("lon2", 0.0f);
        location[1].print();
    }
    preferences.end();
}
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
void loop() {  
    // Serial.println("Handling DNS");

    // Used only in CONFIG mode 
    dnsServer.processNextRequest();
}

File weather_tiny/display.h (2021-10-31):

#ifndef _display_h
#define _display_h

#include <GxEPD.h>
#include "view.h"


struct WindArrow {
    int x = 0, y = 0;
    int scale = 1;
    int offset = -3;
    float deg2rad = 0.01745;

    // 2 triangle coords. Center is (3, 3)
    float x0 = 1 +offset, y0 = 0 +offset;  // top left
    float x1 = 3 +offset, y1 = 2 +offset;  // bottom
    float x2 = 3 +offset, y2 = 6 +offset;  // top
    float x3 = 5 +offset, y3 = 0 +offset;  // top right

    void rotate(int alpha) {
        float rad = alpha * deg2rad;
        Serial.printf("WindArrow rotate by %d deg (%.2f rad)\n", alpha, rad);
        _rotate_point(rad, &x0, &y0);
        _rotate_point(rad, &x1, &y1);
        _rotate_point(rad, &x2, &y2);
        _rotate_point(rad, &x3, &y3);
    }
    
    void draw(int x, int y, GxEPD_Class& display) {
        this->x = x;
        this->y = y;
        display.fillTriangle(x+x0*scale, y+y0*scale, x+x1*scale, y+y1*scale, x+x2*scale, y+y2*scale, GxEPD_BLACK);
        display.fillTriangle(x+x1*scale, y+y1*scale, x+x2*scale, y+y2*scale, x+x3*scale, y+y3*scale, GxEPD_BLACK);
    }


    private:
    
    void _rotate_point(float rad, float *x, float *y) {
        float xc = *x - this->x;
        float yc = *y - this->y;
        
        // p'x = cos(theta) * (px-ox) - sin(theta) * (py-oy) + ox
        // p'y = sin(theta) * (px-ox) + cos(theta) * (py-oy) + oy
        *x = cos(rad) * xc - sin(rad) * yc + this->x;
        *y = sin(rad) * xc + cos(rad) * yc + this->y;

        // Serial.printf("rot %.2f: A(%.2f, %.2f)  B(%.2f, %.2f)  C(%.2f, %.2f)  D(%.2f, %.2f)\n", rad, x0, y0, x1, y1, x2, y2, x3, y3);
    }
} ;


int display_battery_icon(int x, int y, GxEPD_Class& display, int percent) {
    const int icon_width = 24;
    const int icon_height = 12;
    const int bar_width = 6;
    const int bar_height = 8;
    const int bar_margin = 2;
    const int plus_rectangle_width = 4;

    // icon rectangle
    display.drawRect(x, y, icon_width, icon_height, GxEPD_BLACK);

    // the small battery plus-side rectangle
    display.fillRoundRect(x+icon_width-1, y+3, plus_rectangle_width, icon_height-2*3, 2, GxEPD_BLACK);

    // draw charging icon
    if (percent > 100) {
        const int margin = 2;
        const int half_w = icon_width / 2;
        const int half_h = icon_height / 2;

        display.fillTriangle(x-margin+half_w, y+half_h, x-margin+half_w, y+half_h/2, x+half_w+half_w/2, y+half_h, GxEPD_BLACK);
        display.fillTriangle(x+margin+half_w, y+half_h, x+margin+half_w, y+half_h+half_h/2, x+half_w-half_w/2, y+half_h, GxEPD_BLACK);
        return icon_width + plus_rectangle_width;
    }

    // 3-level percent bar
    if (percent > 5) {
        display.fillRect(x+bar_margin+0*(bar_width+1), y+bar_margin, bar_width, bar_height, GxEPD_BLACK);
    }
    if (percent > 35) {
        display.fillRect(x+bar_margin+1*(bar_width+1), y+bar_margin, bar_width, bar_height, GxEPD_BLACK);
    }
    if (percent > 70) {
        display.fillRect(x+bar_margin+2*(bar_width+1), y+bar_margin, bar_width, bar_height, GxEPD_BLACK);
    }
    return icon_width + plus_rectangle_width;
}


int get_text_width(String text) {
    uint16_t width, height;
    int16_t  xb, yb;
    display.getTextBounds(text, display.getCursorX(), display.getCursorY(), &xb, &yb, &width, &height);
    return width;
}


int get_text_height(String text) {
    uint16_t width, height;
    int16_t  xb, yb;
    display.getTextBounds(text, display.getCursorX(), display.getCursorY(), &xb, &yb, &width, &height);
    return height;
}


int position_text(int x, int y, String text) {
    uint16_t width, height;
    int16_t  xb, yb;
    display.getTextBounds(text, x, y, &xb, &yb, &width, &height);
    display.setTextWrap(false);
    display.setTextColor(GxEPD_BLACK);
    display.setCursor(x, y + height);
    return width;
}


void print_text(int x, int y, String text) {
    position_text(x, y, text);
    display.print(text);
}


void print_text(String text) {
    print_text(display.getCursorX(), display.getCursorY(), text);
}


void print_text_y(int y, String text) {
    print_text(display.getCursorX(), y, text);
}


void print_text_x(int x, String text) {
    print_text(x, display.getCursorY(), text);
}


void init_display() {
    Serial.print("init_display...");
    SPI.begin(SPI_CLK, SPI_MISO, SPI_MOSI, ELINK_SS);
    // enable diagnostic output on Serial 
    display.init(115200);
    display.setRotation(3);
    display.setTextWrap(false);
    display.fillScreen(GxEPD_WHITE);
    Serial.println(" completed");
}


void display_config_mode(String network, String pass, String ip) {
    display.setFont(&monofonto18pt7b);
    print_text(50, 0, "Welcome!");
    display.setFont(&Cousine_Regular6pt7b);
    print_text(0, 8, String("Connect to weather station...") + "\nSSID: " + network + "\nPass: " + pass);
    // print_text(0, 65, String("and configure... \n") + "http://" + ip + "/config");
}


void display_validating_mode() {
    display.setFont(&monofonto10pt7b);
    print_text(35, 0, "Validating");
    print_text_x(35, "configuration...");
    display.setFont(&Cousine_Regular6pt7b);
    print_text(35, display.getCursorY()+10, "Please, wait!");
}


void display_header(View& view) {
    display.setFont(&monofonto10pt7b);
    print_text(0, -3, view.location);
    print_text(SCREEN_WIDTH - get_text_width(view.datetime)-3, -12, view.datetime);
    int batt_x = SCREEN_WIDTH - get_text_width(view.datetime) - 33;
    display_battery_icon(batt_x, 3, display, view.battery_percent);
    // display_battery_percentage
    // print_text(batt_x, 3, view.battery_percent_display);  
}
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

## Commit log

2021-05-10 DIY tiny weather station
    [back.stl, btn-left.stl, btn-right.stl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]
2021-10-30 fix ambiguous abs call
    [weather_tiny.ino]
